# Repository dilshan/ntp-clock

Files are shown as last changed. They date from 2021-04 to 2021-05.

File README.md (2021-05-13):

# NTP based digital clock panel

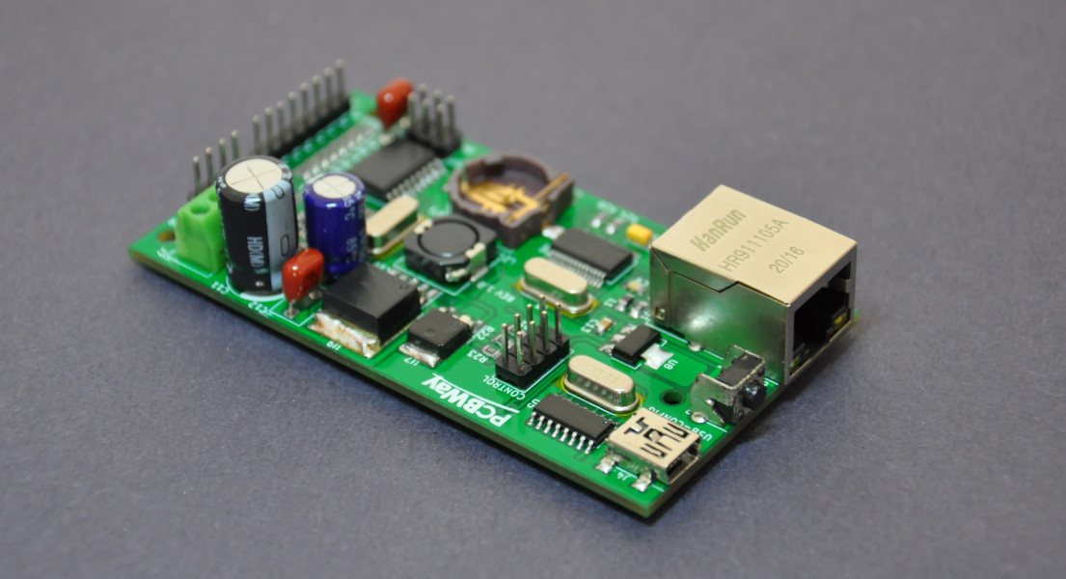
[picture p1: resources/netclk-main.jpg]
Prototype version of NTP clock driver


This project introduces an open-source, *ATmega328* based, configurable [NTP](https://en.wikipedia.org/wiki/Network_Time_Protocol) clock with a 2.3-inch, 7-segment display driver. This clock automatically obtains time from the configured NTP server and updates the date and time of the built-in RTC (*real-time clock*). If the connection to the NTP server is lost, the clock continues to run using its built-in RTC.

All the parameters of this clock can configure using its USB base serial terminal. The firmware of this clock supports both *static* and *DHCP* addressing modes. Apart from that, parameters such as NTP server address, time-offset, and clock display formats can change through the menu-driven configuration terminal.

This clock is designed to drive large common-anode, 7-segment displays. The prototype version is assembled using four individual segments of 7.2V, 2.3-inch, red color displays (*FJS23101BH*). To archive, the necessary high output voltage and the current, the 7-segment display output stage of this clock is formed using *ULN2803* Darlington transistor array and *BC858* transistors.

The network component of this clock is built around the *ENC28J60* 10BASE-T stand-alone Ethernet controller.

Highly accurate *DS3231M* RTC is using in this clock for time-keeping operations. To backup the date and time, the *CR1220* type button cell is included in the PCB. The date and time are syncs with the NTP server during the system startup. Users can manually initiate synchronization by pressing the "*SYNC*" button in the system.

Depending on the NTP server, the user needs to specify the time offset to the system to get the correct local time. Time offset can configure using the system configuration menu, and it must be input in a standard format like *+5:30*.

Firmware of this clock is developed using the [Arduino framework](https://www.arduino.cc/en/software) and libraries.

[**PCBWay**](https://www.pcbway.com) provides sponsorship for this project. The [PCBWay online ordering service](https://www.pcbway.com/orderonline.aspx) provides excellent help to fabricate this PCB. We got finished PCBs within three days, and the quality of the service is at a superior level. PCB of this project can directly [order from PCBWay through this link](https://www.pcbway.com/project/shareproject/NTP_based_digital_clock_panel.html).

This project is a [certified](https://certification.oshwa.org/lk000009.html) open-source hardware project. All the content of this project are distributed under the terms of the following license:

- Hardware License: [CC BY 4.0](https://creativecommons.org/licenses/by/4.0/)
- Software and firmware License: [MIT](https://github.com/dilshan/ntp-clock/blob/main/LICENSE)
- [Documentation](https://github.com/dilshan/ntp-clock/wiki) License: [CC BY 4.0](https://creativecommons.org/licenses/by/4.0/)

LK000009 (https://certification.oshwa.org/lk000009.html)

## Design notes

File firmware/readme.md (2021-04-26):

To compile the firmware following libraries must install into the Arduino IDE:

- [EtherCard](https://github.com/njh/EtherCard)
- [DS3231 library for the Arduino - *ds3231FS*](https://github.com/rodan/ds3231)
- [jm_PCF8574 Arduino Library](https://github.com/jmparatte/jm_PCF8574)

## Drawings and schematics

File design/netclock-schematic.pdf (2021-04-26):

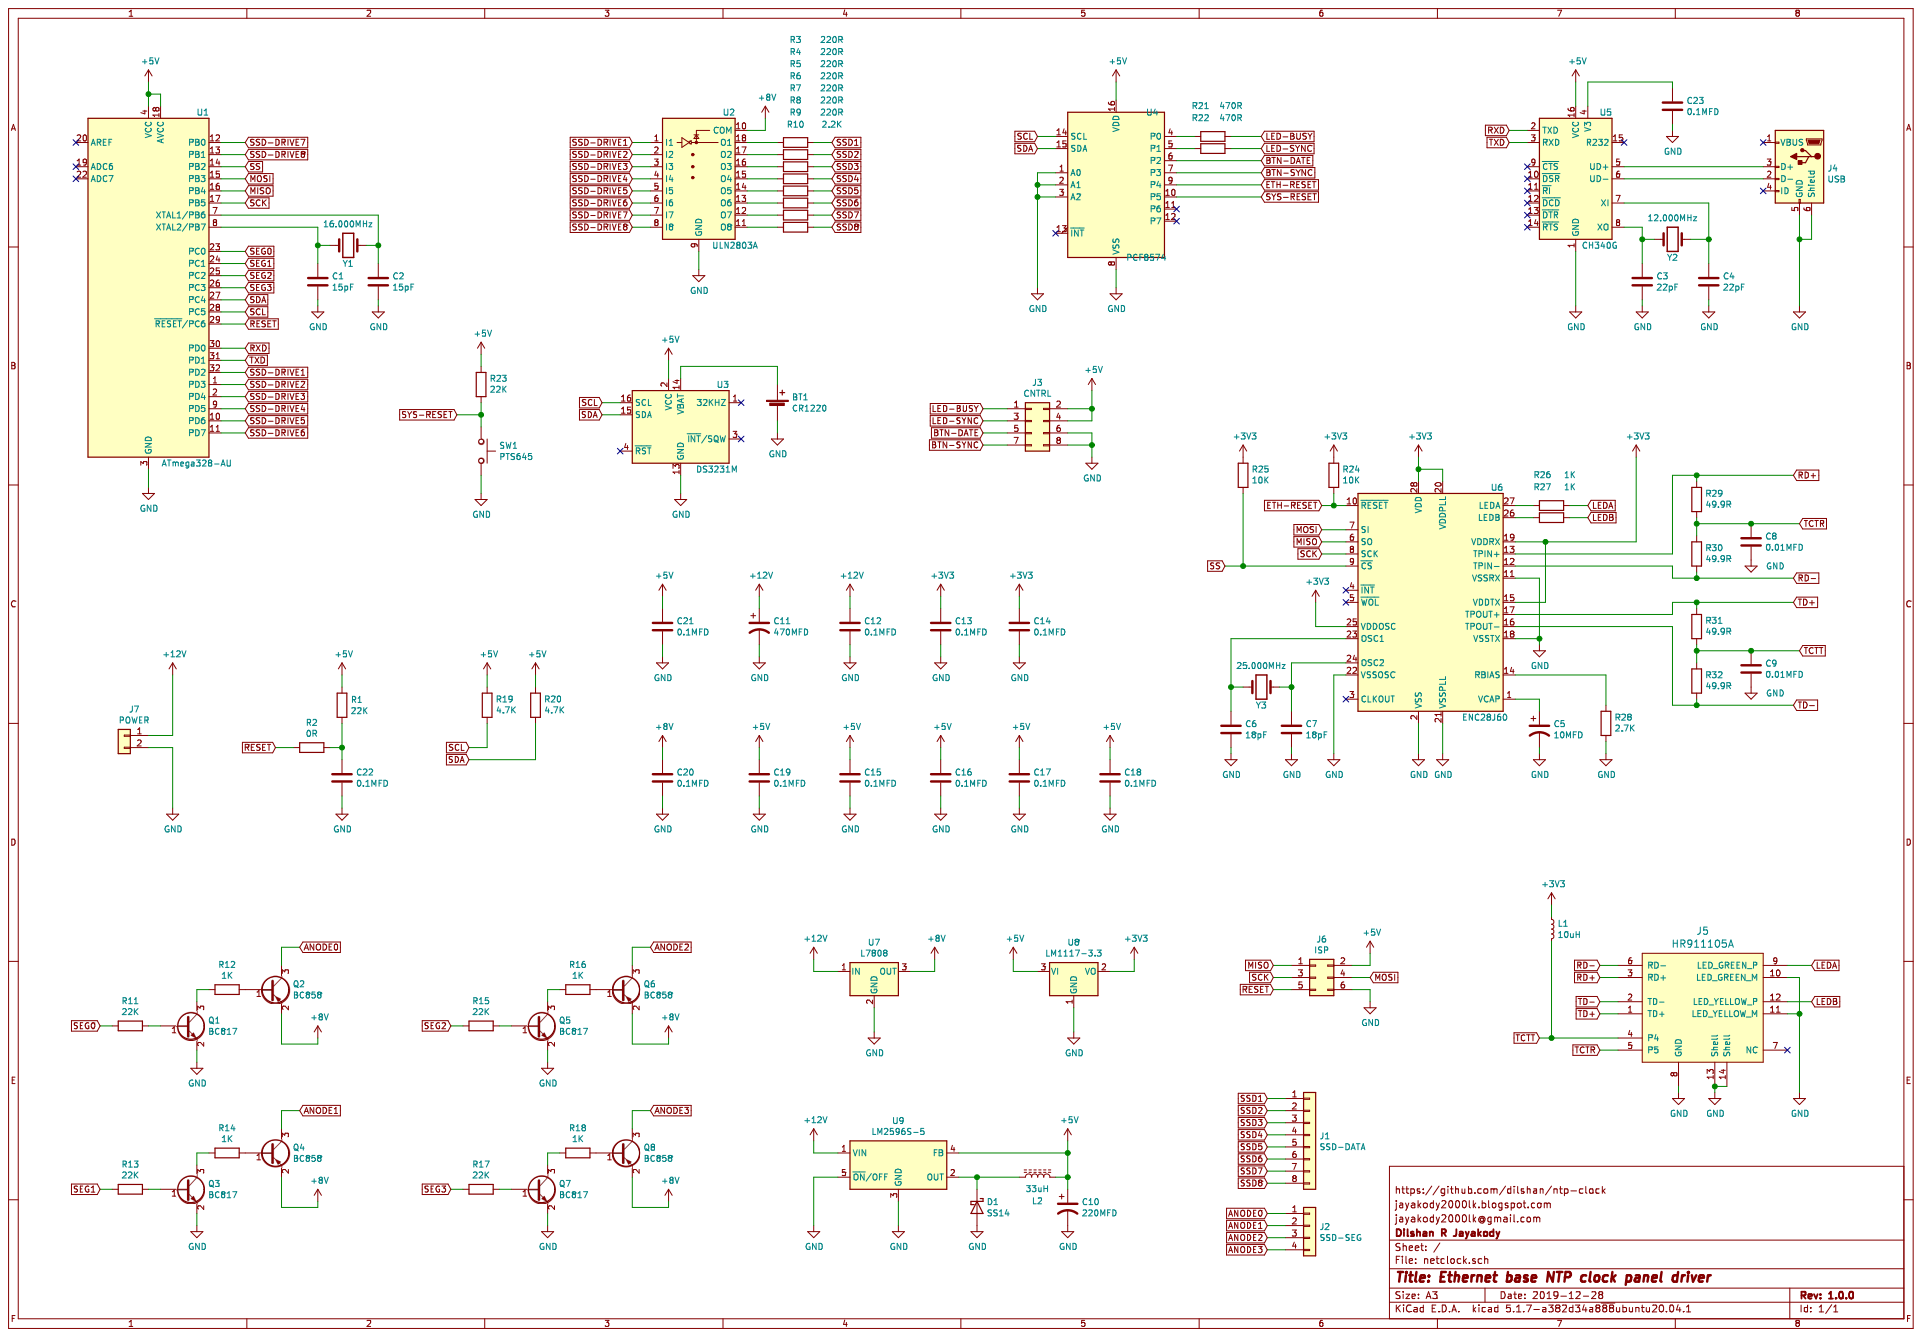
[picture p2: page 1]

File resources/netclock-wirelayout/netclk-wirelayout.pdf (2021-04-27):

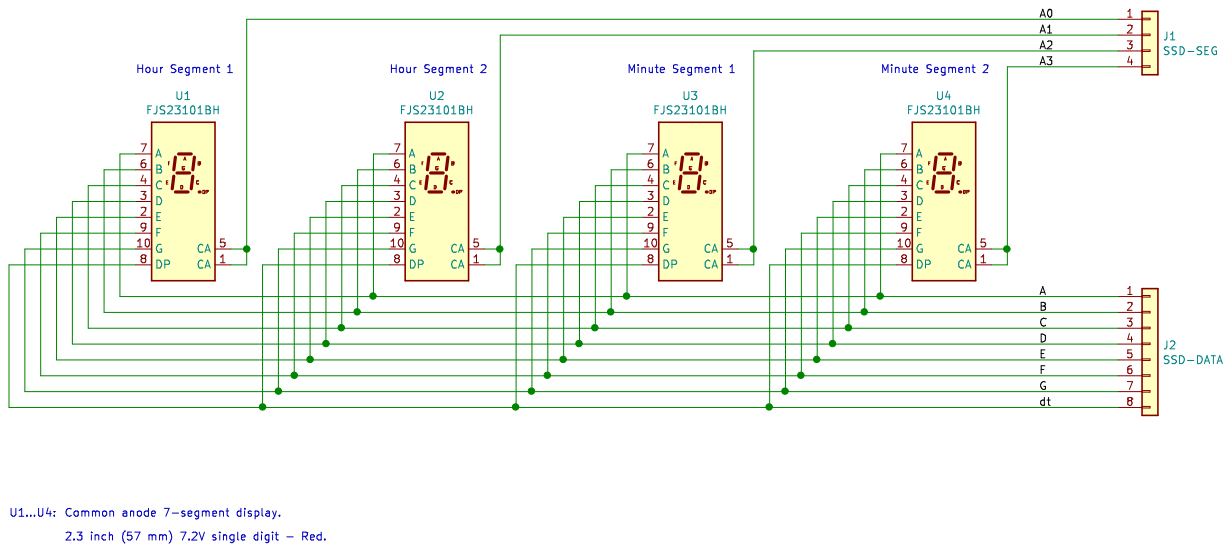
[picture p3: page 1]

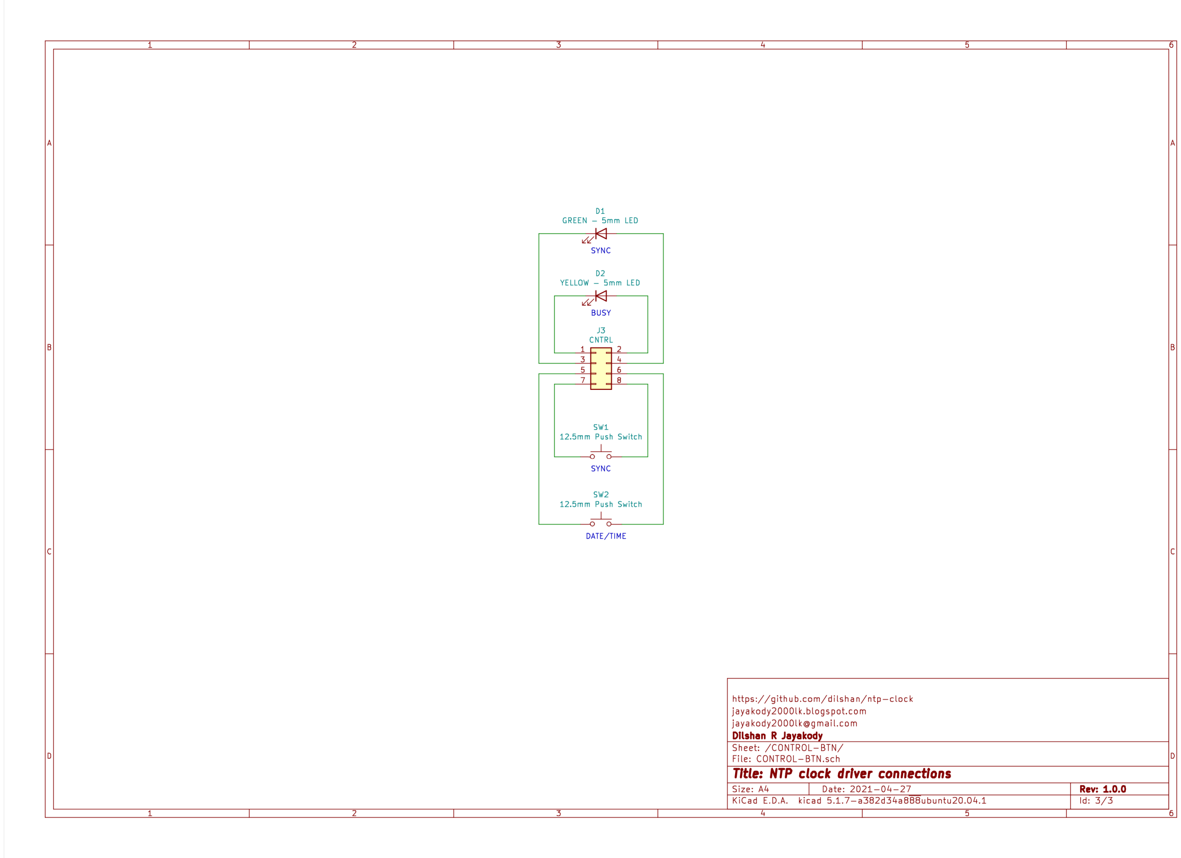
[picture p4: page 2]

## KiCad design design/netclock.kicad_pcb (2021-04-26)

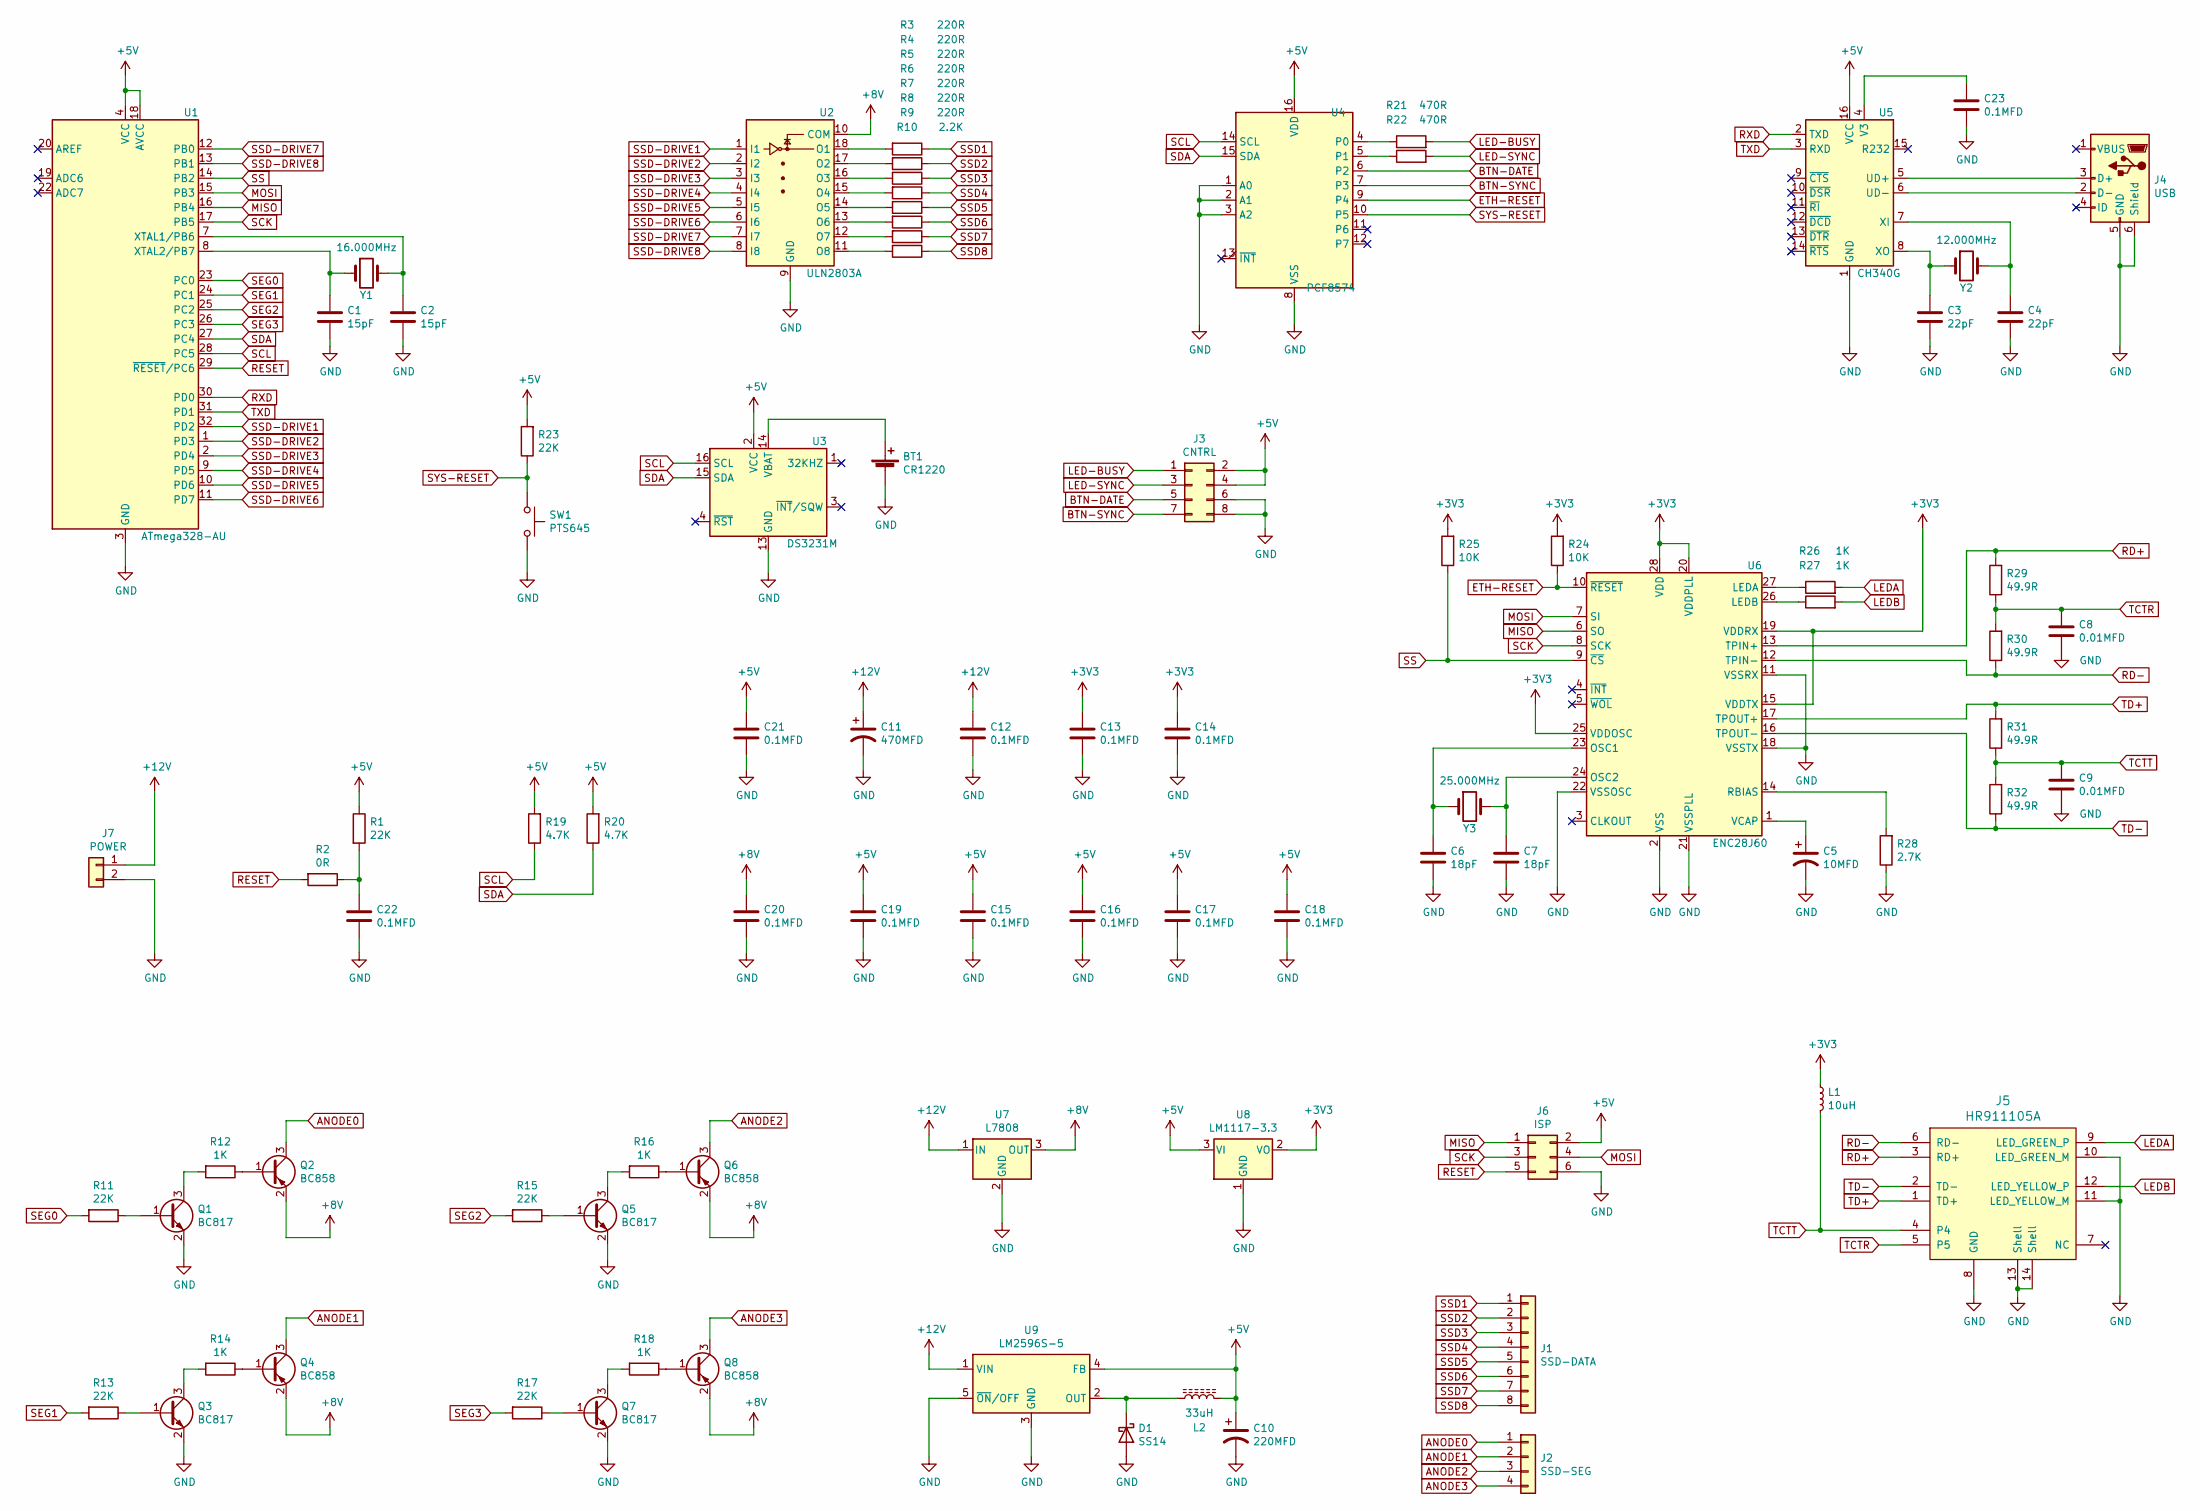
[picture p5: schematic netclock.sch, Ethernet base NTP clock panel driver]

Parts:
BT1: CR1220; BAT_BC501SM
C1, C2: 15pF; C_0805_2012Metric_Pad1.15x1.40mm_HandSolder
C3, C4: 22pF; C_0805_2012Metric_Pad1.15x1.40mm_HandSolder
C5: 10MFD; CP_EIA-3216-18_Kemet-A_Pad1.58x1.35mm_HandSolder
C6, C7: 18pF; C_0805_2012Metric_Pad1.15x1.40mm_HandSolder
C8, C9: 0.01MFD; C_0805_2012Metric_Pad1.15x1.40mm_HandSolder
C10: 220MFD; CP_Radial_D8.0mm_P5.00mm
C11: 470MFD; CP_Radial_D10.0mm_P5.00mm
C12: 0.1MFD; C_Disc_D7.5mm_W5.0mm_P5.00mm
C13, C14, C15, C16, C17, C18, C19, C21, C22, C23: 0.1MFD; C_0805_2012Metric_Pad1.15x1.40mm_HandSolder
C20: 0.1MFD; C_Disc_D6.0mm_W4.4mm_P5.00mm
D1: SS14; D_SMA
J1: SSD-DATA; PinHeader_1x08_P2.54mm_Vertical
J2: SSD-SEG; PinHeader_1x04_P2.54mm_Vertical
J3: CNTRL; PinHeader_2x04_P2.54mm_Vertical
J4: USB; USB_Mini-B_Lumberg_2486_01_Horizontal
J5: HR911105A; HR911105a
J6: ISP; PinHeader_2x03_P2.54mm_Vertical
J7: POWER; PhoenixContact_MCV_1,5_2-G-3.5_1x02_P3.50mm_Vertical
L1: 10uH; L_0805_2012Metric_Pad1.15x1.40mm_HandSolder
L2: 33uH; L_10.4x10.4_H4.8
Q1, Q3, Q5, Q7: BC817; SOT-23
Q2, Q4, Q6, Q8: BC858; SOT-23
R1, R11, R13, R15, R17, R23: 22K; R_0805_2012Metric_Pad1.15x1.40mm_HandSolder
R2: 0R; R_0805_2012Metric_Pad1.15x1.40mm_HandSolder
R3, R4, R5, R6, R7, R8, R9: 220R; R_0805_2012Metric_Pad1.15x1.40mm_HandSolder
R10: 2.2K; R_0805_2012Metric_Pad1.15x1.40mm_HandSolder
R12, R14, R16, R18, R26, R27: 1K; R_0805_2012Metric_Pad1.15x1.40mm_HandSolder
R19, R20: 4.7K; R_0805_2012Metric_Pad1.15x1.40mm_HandSolder
R21, R22: 470R; R_0805_2012Metric_Pad1.15x1.40mm_HandSolder
R24, R25: 10K; R_0805_2012Metric_Pad1.15x1.40mm_HandSolder
R28: 2.7K; R_0805_2012Metric_Pad1.15x1.40mm_HandSolder
R29, R30, R31, R32: 49.9R; R_0805_2012Metric_Pad1.15x1.40mm_HandSolder
SW1: PTS645; SW_Tactile_SPST_Angled_PTS645Vx31-2LFS
U1: ATmega328-AU; TQFP-32_7x7mm_P0.8mm
U2: ULN2803A; SOIC-18W_7.5x11.6mm_P1.27mm
U3: DS3231M; SOIC-16W_7.5x10.3mm_P1.27mm
U4: PCF8574; SOIC-16W_7.5x10.3mm_P1.27mm
U5: CH340G; SOIC-16_3.9x9.9mm_P1.27mm
U6: ENC28J60; SSOP-28_5.3x10.2mm_P0.65mm
U7: L7808; TO-252-3_TabPin2
U8: LM1117-3.3; SOT-223-3_TabPin2
U9: LM2596S-5; TO-263-5_TabPin3
Y1: 16.000MHz; Crystal_HC49-U_Vertical
Y2: 12.000MHz; Crystal_HC49-U_Vertical
Y3: 25.000MHz; Crystal_HC49-U_Vertical

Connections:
+3V3: C13.1, C14.1, L1.1, R24.2, R25.2, U6.15 (VDDTX), U6.19 (VDDRX), U6.20 (VDDPLL), U6.25 (VDDOSC), U6.28 (VDD), U8.2 (VO)
+5V: C10.1, C15.1, C16.1, C17.1, C18.1, C19.1, C21.1, J3.2, J3.4, J6.2, L2.2, R1.1, R19.2, R20.2, R23.2, U1.4 (VCC), U1.6 (VCC), U1.18 (AVCC), U3.2 (VCC), U4.16 (VDD), U5.16 (VCC), U8.3 (VI), U9.4 (FB)
+8V: C20.1, Q2.2 (E), Q4.2 (E), Q6.2 (E), Q8.2 (E), U2.10 (COM), U7.3 (OUT)
+12V: C11.1, C12.1, J7.1, U7.1 (IN), U9.1 (VIN)
ANODE0: J2.1, Q2.3 (C)
ANODE1: J2.2, Q4.3 (C)
ANODE2: J2.3, Q6.3 (C)
ANODE3: J2.4, Q8.3 (C)
BTN-DATE: J3.5, U4.6 (P2)
BTN-SYNC: J3.7, U4.7 (P3)
ETH-RESET: R24.1, U4.9 (P4), U6.10 (~RESET)
GND: BT1.2 (-), C1.2, C2.2, C3.2, C4.2, C5.2, C6.2, C7.2, C8.2, C9.2, C10.2, C11.2, C12.2, C13.2, C14.2, C15.2, C16.2, C17.2, C18.2, C19.2, C20.2, C21.2, C22.2, C23.2, D1.2 (A), J3.6, J3.8, J4.5 (GND), J4.6 (Shield), J5.8 (GND), J5.10 (LED_GREEN_M), J5.11 (LED_YELLOW_M), J5.13 (Shell), J5.14 (Shell), J6.6, J7.2, Q1.2 (E), Q3.2 (E), Q5.2 (E), Q7.2 (E), R28.1, SW1.2, U1.3 (GND), U1.5 (GND), U1.21 (GND), U2.9 (GND), U3.5 (GND), U3.6 (GND), U3.7 (GND), U3.8 (GND), U3.9 (GND), U3.10 (GND), U3.11 (GND), U3.12 (GND), U3.13 (GND), U4.1 (A0), U4.2 (A1), U4.3 (A2), U4.8 (VSS), U5.1 (GND), U6.2 (VSS), U6.11 (VSSRX), U6.18 (VSSTX), U6.21 (VSSPLL), U6.22 (VSSOSC), U7.2 (GND), U8.1 (GND), U9.3 (GND), U9.5 (~ON~/OFF)
LED-BUSY: J3.1, R21.2
LED-SYNC: J3.3, R22.2
LEDA: J5.9 (LED_GREEN_P), R27.2
LEDB: J5.12 (LED_YELLOW_P), R26.2
MISO: J6.1, U1.16 (PB4), U6.6 (SO)
MOSI: J6.4, U1.15 (PB3), U6.7 (SI)
unnamed: BT1.1 (+), U3.14 (VBAT)
unnamed: C1.1, U1.8 (XTAL2/PB7), Y1.1
unnamed: C2.1, U1.7 (XTAL1/PB6), Y1.2
unnamed: C3.1, U5.8 (XO), Y2.1
unnamed: C4.1, U5.7 (XI), Y2.2
unnamed: C5.1, U6.1 (VCAP)
unnamed: C6.1, U6.23 (OSC1), Y3.1
unnamed: C7.1, U6.24 (OSC2), Y3.2
unnamed: C22.1, R1.2, R2.1
unnamed: C23.1, U5.4 (V3)
unnamed: D1.1 (K), L2.1, U9.2 (OUT)
unnamed: J4.2 (D-), U5.6 (UD-)
unnamed: J4.3 (D+), U5.5 (UD+)
unnamed: Q1.1 (B), R11.1
unnamed: Q1.3 (C), R12.2
unnamed: Q2.1 (B), R12.1
unnamed: Q3.1 (B), R13.1
unnamed: Q3.3 (C), R14.2
unnamed: Q4.1 (B), R14.1
unnamed: Q5.1 (B), R15.1
unnamed: Q5.3 (C), R16.2
unnamed: Q6.1 (B), R16.1
unnamed: Q7.1 (B), R17.1
unnamed: Q7.3 (C), R18.2
unnamed: Q8.1 (B), R18.1
unnamed: R3.2, U2.18 (O1)
unnamed: R4.2, U2.17 (O2)
unnamed: R5.2, U2.16 (O3)
unnamed: R6.2, U2.15 (O4)
unnamed: R7.2, U2.14 (O5)
unnamed: R8.2, U2.13 (O6)
unnamed: R9.2, U2.12 (O7)
unnamed: R10.2, U2.11 (O8)
unnamed: R21.1, U4.4 (P0)
unnamed: R22.1, U4.5 (P1)
unnamed: R26.1, U6.26 (LEDB)
unnamed: R27.1, U6.27 (LEDA)
unnamed: R28.2, U6.14 (RBIAS)
RD+: J5.3 (RD+), R29.2, U6.13 (TPIN+)
RD-: J5.6 (RD-), R30.1, U6.12 (TPIN-)
RESET: J6.5, R2.2, U1.29 (~RESET~/PC6)
RXD: U1.30 (PD0), U5.2 (TXD)
SCK: J6.3, U1.17 (PB5), U6.8 (SCK)
SCL: R19.1, U1.28 (PC5), U3.16 (SCL), U4.14 (SCL)
SDA: R20.1, U1.27 (PC4), U3.15 (SDA), U4.15 (SDA)
SEG0: R11.2, U1.23 (PC0)
SEG1: R13.2, U1.24 (PC1)
SEG2: R15.2, U1.25 (PC2)
SEG3: R17.2, U1.26 (PC3)
SS: R25.1, U1.14 (PB2), U6.9 (~CS)
SSD1: J1.1, R3.1
SSD2: J1.2, R4.1
SSD3: J1.3, R5.1
SSD4: J1.4, R6.1
SSD5: J1.5, R7.1
SSD6: J1.6, R8.1
SSD7: J1.7, R9.1
SSD8: J1.8, R10.1
SSD-DRIVE1: U1.32 (PD2), U2.1 (I1)
SSD-DRIVE2: U1.1 (PD3), U2.2 (I2)
SSD-DRIVE3: U1.2 (PD4), U2.3 (I3)
SSD-DRIVE4: U1.9 (PD5), U2.4 (I4)
SSD-DRIVE5: U1.10 (PD6), U2.5 (I5)
SSD-DRIVE6: U1.11 (PD7), U2.6 (I6)
SSD-DRIVE7: U1.12 (PB0), U2.7 (I7)
SSD-DRIVE8: U1.13 (PB1), U2.8 (I8)
SYS-RESET: R23.1, SW1.1, U4.10 (P5)
TCTR: C8.1, J5.5, R29.1, R30.2
TCTT: C9.1, J5.4, L1.2, R31.1, R32.2
TD+: J5.1 (TD+), R31.2, U6.17 (TPOUT+)
TD-: J5.2 (TD-), R32.1, U6.16 (TPOUT-)
TXD: U1.31 (PD1), U5.3 (RXD)

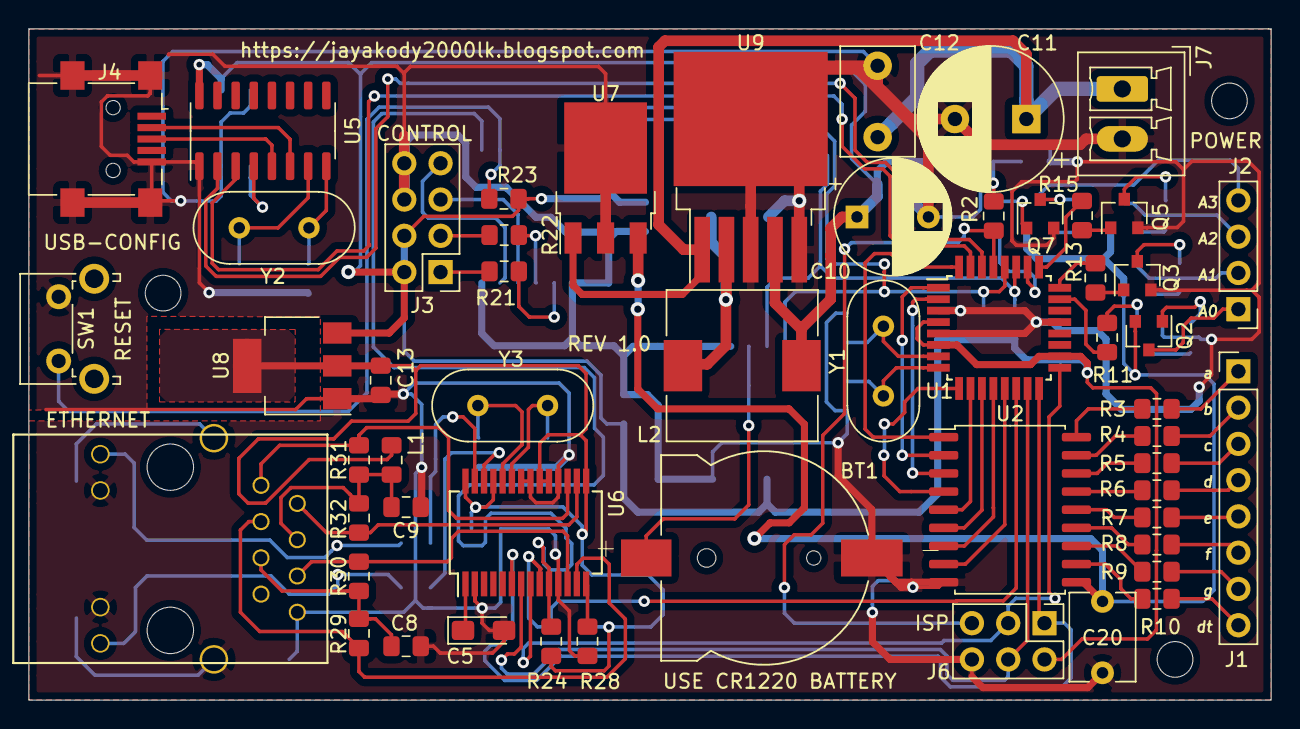
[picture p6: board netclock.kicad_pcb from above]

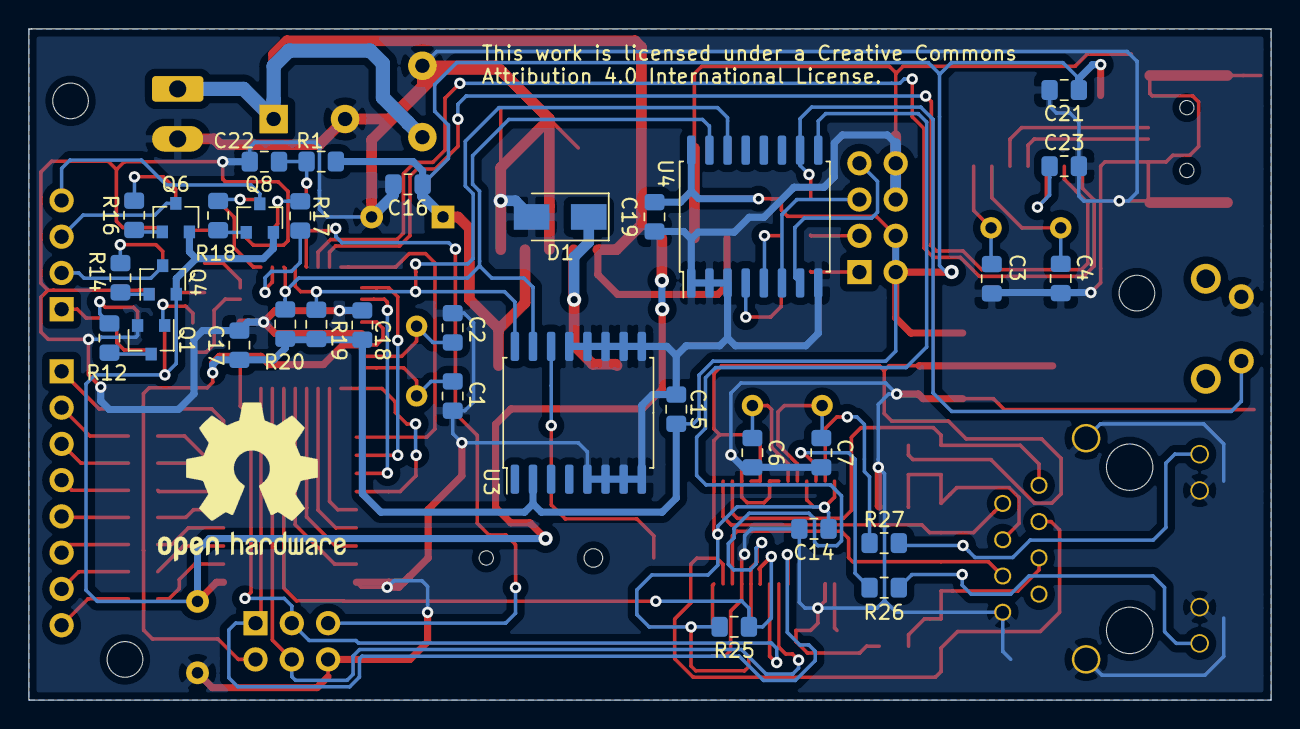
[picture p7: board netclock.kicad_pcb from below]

Board: 2 copper layers, 87.0 x 47.0 mm, 91 parts (34 on the bottom side), 90 nets.

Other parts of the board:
 : OSHW-Logo2_14.6x12mm_SilkScreen
 #2,  #3,  #4: MountingHole_2.5mm

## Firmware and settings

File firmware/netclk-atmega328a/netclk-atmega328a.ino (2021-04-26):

//---------------------------------------------------------------------------------------
// Ethernet base NTP clock panel driver.
// Main Arduino sketch.
// 
// Copyright (c) 2021 Dilshan R Jayakody. [jayakody2000lk@gmail.com]
// 
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
#include <Wire.h>
#include <EtherCard.h>
#include <ds3231.h>

#include "netclkdisplay.h"
#include "netclkintf.h"
#include "netclkstorage.h"
#include "netclkutil.h"

// Use NIST Internet Time Server (time-a-g.nist.gov).
#define DEFAULT_NTP_PORT  123
#define DEFAULT_NTP_SERVER  {129, 6, 15, 28}

// Unix timestamp for 1st of January, 1970 (UTC).
#define UNIX_TIMESTAMP  2208988800UL
#define BASE_YEAR       1970

#define LEAP_YEAR(Y)  (((BASE_YEAR+(Y))>0) && !((BASE_YEAR+(Y))%4) && (((BASE_YEAR+(Y))%100) || !((BASE_YEAR+(Y))%400)))
#define NEW_LINE      Serial.println(F(" "))

// Device MAC address generated by  Ian Campbell's MAC address generator
// at https://www.hellion.org.uk/cgi-bin/randmac.pl.
static const unsigned char DEV_MAC[] = {0x3A, 0xF5, 0x42, 0x21, 0x96, 0x33};

// Number of days in each month.
static const unsigned char monthDays[] = {31, 28, 31, 30, 31, 30, 31, 31, 30, 31, 30, 31};

bool isNetworkAvailable;
bool clock24hrFormat;
bool initalBoot;
static volatile bool updateReq;

unsigned char syncButtonState;
unsigned char dateButtonState;
unsigned char displayTimeout;

unsigned char ntpServer[] = DEFAULT_NTP_SERVER;
unsigned char ntpPort = DEFAULT_NTP_PORT;
unsigned char Ethernet::buffer[450];

static unsigned char displayVal[3];

long timeZoneOffset = 0L;

struct ts systime;
SystemConfig sysconf;
static volatile DISPLAY_MODE displayMode;

void resetSysConfig()
{
  SystemConfig resetConfig;
  const unsigned char resetNTPIP[] = DEFAULT_NTP_SERVER;

  setDefaultConfig(&resetConfig);

  // Network type is set to DHCP and set static IP configuration entries.
  configWriteNetworkType(resetConfig.networkType);
  configWriteDeviceIP(resetConfig.deviceIP);
  configWriteSubnetMask(resetConfig.netmask);
  configWriteGateway(resetConfig.gateway);

  // Set default NTP server configuration.
  configureNTPInfo(resetNTPIP, DEFAULT_NTP_PORT);

  // Reset time zone to 0:00.
  writeTimeOffset(0L);

  // Time display format is set to 24-hour.
  writeDisplayFormat(true);

  delay(100);
}

void initSystem()
{
  setDefaultConfig(&sysconf);

  // Setup seven segment display interface.
  initDisplay();

  // Setup serial communication interface with baud rate of 9600 and 8N1 configuration.
  Serial.begin(9600);
  Serial.println(F("Starting up the system..."));

  // Setup I2C interface.
  Wire.begin();

  // Setup PCF8574 I/O expander and it's I/O ports.
  delay(100);
  initInterface();
  setIndicator(IND_BUSY_CONFIG, true);

  // Check for factory reset input.
  if (!getFactorResetState())
  {
    // Perform configuration reset.
    Serial.println(F("Reseting system to default configuration..."));
    resetSysConfig();

    // Wait until user releases reset jumper.
    while (!getFactorResetState())
    {
      setIndicator(IND_BUSY_CONFIG, false);
      delay(250);
      setIndicator(IND_BUSY_CONFIG, true);
      delay(250);
    }

    // Perform system restart.
    rebootSystem();
  }

  // Load system configuration from EEPROM.
  Serial.println(F("Reading system configuration..."));
  configRead(&sysconf);
  readNTPConfigInfo(ntpServer, &ntpPort);

  // Validate NTP configuration.
  if ((ntpServer[0] == 0xFF) && (ntpServer[1] == 0xFF) && (ntpServer[2] == 0xFF) && (ntpServer[3] == 0xFF))
  {
    // EEPROM default is loaded. Fix NTP IP address and port to default values.
    Serial.println(F("Switching NTP server configuration to defaults..."));
    unsigned char tempDefaultIP[] = DEFAULT_NTP_SERVER;
    memcpy(ntpServer, tempDefaultIP, 4);
    ntpPort = DEFAULT_NTP_PORT;
  }

  // Setup ethernet controller.
  Serial.println(F("Connecting to network..."));
  ether.begin(sizeof Ethernet::buffer, DEV_MAC, SS);
}

void configureDHCP(SystemConfig *config)
{
  config->networkType = NET_TYPE_DHCP;
  configWriteNetworkType(NET_TYPE_DHCP);

  Serial.println(F("Configuration updated with DHCP settings."));
}

bool configureStaticIP(SystemConfig *config)
{
  // Prompt IP address, subnet mask and gatway IP address inputs to user.
  Serial.print(F("Device IP address: "));
  if (!inputIpAddress(config->deviceIP))
  {
    return false;
  }

  Serial.print(F("\n\n\rSubnet mask: "));
  if (!inputIpAddress(config->netmask))
  {
    return false;
  }

  Serial.print(F("\n\n\rGateway IP address: "));
  if (!inputIpAddress(config->gateway))
  {
    return false;
  }

  NEW_LINE;

  // Write configuration changes to EEPROM.
  config->networkType = NET_TYPE_STATIC;
  configWriteNetworkType(NET_TYPE_STATIC);
  configWriteDeviceIP(config->deviceIP);
  configWriteSubnetMask(config->netmask);
  configWriteGateway(config->gateway);

  Serial.println(F("Configuration updated with static IP address."));
  return true;
}

bool configureNTPServer(unsigned char* ntpIpAddr, unsigned char* ntpPort)
{
  unsigned char tempIp[4] = DEFAULT_NTP_SERVER;
  unsigned char tempPort = DEFAULT_NTP_PORT;

  int retryAttempt = 60;
  unsigned long ntpTempVal = 0;

  // Prompt NTP IP address.
  Serial.print(F("NTP server IP address: "));
  if (!inputIpAddress(tempIp))
  {
    return false;
  }

  // Prompt NTP port.
  Serial.print(F("\n\n\rNTP server port: "));
  if (!inputPort(&tempPort, DEFAULT_NTP_PORT))
  {
    return false;
  }

  // Verify specified NTP server.
  Serial.println(F("\n\n\rConnecting with the specified NTP server..."));
  while (retryAttempt > 0)
  {
    ether.ntpRequest(tempIp, tempPort);
    Serial.print(".");
    word length = ether.packetReceive();
    ether.packetLoop(length);
    if (length > 0 && ether.ntpProcessAnswer(&ntpTempVal, tempPort))
    {
      // NTP request is completed.
      Serial.println(F("\n\rReceived data from NTP server\n\r"));
      break;
    }

    delay(500);
    retryAttempt--;
  }

  // Validate response received from the request.
  if (ntpTempVal > 0)
  {
    // NTP request is successful.
    memcpy(ntpIpAddr, tempIp, 4);
    *ntpPort = tempPort;
    return true;
  }
  else
  {
    // NTP request is failed.
    Serial.println(F("\n\rNTP request is failed or invalid!\n\r"));
    return false;
  }
}

bool setDisplayFormat()
{
  bool isContinue = true;
  char inKey;

  while (isContinue)
  {
    inKey = 0;

    Serial.println(F("1. Display time in 24-hour format"));
    Serial.println(F("2. Display time in 12-hour format"));
    Serial.println("");
    Serial.print(F("Selection [1..2]: "));

    inKey = getKeyInput(0x30, 0x33);
    {
      if (inKey == 0x1B)
      {
        // User cancel the current operation.
        return false;
      }
    }

    Serial.println(inKey);

    // Allow key option 1 or 2 only.
    isContinue = !((inKey > 0x30) && (inKey < 0x33));
  }

  clock24hrFormat = (inKey == 0x31);
  return true;
}

void systemMenu()
{
  bool isContinue = true;
  char inKey;
  long tempTimeZone;

  // Initialize menu system and start menu service loop.
  setIndicator(IND_BUSY_CONFIG, true);
  NEW_LINE;

  while (isContinue)
  {
    inKey = 0;

    Serial.println(F("1. Configure for DHCP network"));
    Serial.println(F("2. Configure with static IP address"));
    Serial.println(F("3. Show network configuration"));
    Serial.println(F("4. Synchronize date/time"));
    Serial.println(F("5. Set time offset"));
    Serial.println(F("6. Show current date/time"));
    Serial.println(F("7. Configure NTP server"));
    Serial.println(F("8. Configure clock display format"));
    Serial.println(F("9. Exit"));
    Serial.println(F("0. Exit and restart"));
    Serial.println("");
    Serial.print(F("Selection [0..9]: "));

    inKey = getKeyInput(0x2F, 0x3A);

    if ((inKey > 0x2F) && (inKey < 0x3A))
    {
      Serial.println(inKey);
      NEW_LINE;
    }

    switch (inKey)
    {
      case 0x31:
        // Configure for DHCP network.
        configureDHCP(&sysconf);
        Serial.println(F("Restarting the system to apply the network changes..."));
        rebootSystem();
        break;
      case 0x32:
        // Configure with static IP address.
        if (configureStaticIP(&sysconf))
        {
          // Static IP configuration is completed.
          Serial.println(F("Restarting the system to apply the network changes..."));
          rebootSystem();
        }
        else
        {
          // Static IP configuration is canceled by the user.
          Serial.println(F("\n\n"));
        }
        break;
      case 0x33:
        // Show network configuration.
        showNetworkInfo();
        break;
      case 0x34:
        // Synchronize date/time.
        clearDisplay();
        syncSystemTime();
        NEW_LINE;
        break;
      case 0x35:
        // Set time offset.
        Serial.print(F("Time offset relative to UTC/GMT [e.g: +5:30]: "));
        tempTimeZone = inputTimeZone();
        NEW_LINE;
        if (tempTimeZone != 1)
        {
          // Time zone configuration is completed.
          timeZoneOffset = tempTimeZone;
          writeTimeOffset(timeZoneOffset);
          Serial.println(F("Restarting the system to apply the time offset change..."));
          rebootSystem();
        }
        else
        {
          // Time zone configuration is canceled by the user.
          NEW_LINE;
        }
        break;
      case 0x36:
        // Show current date/time.
        printCurrentTimeConfig();
        NEW_LINE;
        break;
      case 0x37:
        // Configure NTP server.
        if (configureNTPServer(ntpServer, &ntpPort))
        {
          // NTP server configuration is completed.
          configureNTPInfo(ntpServer, ntpPort);
        }
        else
        {
          // NTP server configuration is canceled by the user.
          Serial.println(F("\n\n"));
        }
        break;
      case 0x38:
        // Configure clock display format.
        if (setDisplayFormat())
        {
          writeDisplayFormat(clock24hrFormat);
        }
        NEW_LINE;
        break;
      case 0x39:
      case 0x1B:
        // Exit.
        isContinue = false;
        break;
      case 0x30:
        // Exit and restart.
        Serial.println("");
        rebootSystem();
        break;
    }
  }

  // Leaving from configuration menu system.
  NEW_LINE;
  updateReq = true;
  displayMode = DISP_TIME;
  setIndicator(IND_BUSY_CONFIG, false);
}

unsigned long getTimeFromServer()
{
  unsigned long timeFromNTP;

  int retryAttempt = 60;
  while (retryAttempt > 0)
  {
    ether.ntpRequest(ntpServer, ntpPort);
    Serial.print(".");
    word length = ether.packetReceive();
    ether.packetLoop(length);
    if (length > 0 && ether.ntpProcessAnswer(&timeFromNTP, ntpPort))
    {
      // NTP request is successful.
      Serial.println();
      Serial.println(F("Received time from server"));
      return timeFromNTP - UNIX_TIMESTAMP + timeZoneOffset;
    }

    delay(500);
    retryAttempt--;
  }

  return 0;
}

void epochToTime(unsigned long time, struct ts* outTime)
{
  unsigned char year;
  unsigned char month, monthLength;
  unsigned long days;

  // Extract time components from specified data.
  outTime->sec = time % 60;
  time /= 60;

  outTime->min = time % 60;
  time /= 60;

  outTime->hour = time % 24;
  time /= 24;

  year = 0;
  days = 0;

  // Calculate year from 1970.
  while ((unsigned)(days += (LEAP_YEAR(year) ? 366 : 365)) <= time)
  {
    year++;
  }

  outTime->year = year + BASE_YEAR;

  days -= LEAP_YEAR(year) ? 366 : 365;
  time -= days;

  days = 0;
  monthLength = 0;

  for (month = 0; month < 12; month++)
  {
    if (month == 1)
    {
      // Determine days in month of february based on leap year.
      monthLength = LEAP_YEAR(year) ? 29 : 28;
    }
    else
    {
      monthLength = monthDays[month];
    }

    if (time >= monthLength)
    {
      time -= monthLength;
    }
    else
    {
      break;
    }
  }

  outTime->mon = month + 1;
  outTime->mday = time + 1;
}

void showNetworkInfo()
{
  // Show status of the network connectivity.
  Serial.print(F("Network connection: "));
  if (isNetworkAvailable)
  {
    // Network connection is active.
    Serial.println(F("UP"));
    ether.printIp("Device IP address: ", ether.myip);
    ether.printIp("Netmask: ", ether.netmask);
    ether.printIp("Gateway IP address: ", ether.gwip);
    ether.printIp("DNS IP address: ", ether.dnsip);
  }
  else
  {
    // Network connection is down!
    Serial.println(F("DOWN"));
  }

  ether.printIp("NTP server: ", ntpServer);
  Serial.print(F("NTP server port: "));
  Serial.println(ntpPort);
  NEW_LINE;
}

void syncSystemTime()
{
  setIndicator(IND_SYNC, true);
  Serial.println(F("Trying to synchronize time with server..."));

  // Create DHCP or static IP based network connection.
  if (!isNetworkAvailable)
  {
    if (!initalBoot)
    {
      // If network is not available we need to restart the ENC28J64 controller.
      Serial.println(F("Connecting to network..."));
      resetEthernet();
      delay(1000);
      ether.begin(sizeof Ethernet::buffer, DEV_MAC, SS);
      delay(200);
    }

    // Try to create network connection.
    if (sysconf.networkType == NET_TYPE_DHCP)
    {
      // Create DHCP network connection.
      Serial.println(F("Requesting DHCP network connection"));
      isNetworkAvailable = ether.dhcpSetup();
      if (!isNetworkAvailable)
      {
        Serial.println(F("** Fail to create network connection! **"));
      }
    }
    else
    {
      // Create network connection with specified static IP.
      Serial.println(F("Configuring static IP connection"));
      isNetworkAvailable = ether.staticSetup(sysconf.deviceIP, sysconf.gateway, NULL, sysconf.netmask);
    }

    ether.printIp("- Device IP address: ", ether.myip);
    ether.printIp("- Netmask: ", ether.netmask);
    ether.printIp("- Gateway IP address: ", ether.gwip);
    ether.printIp("- DNS IP address: ", ether.dnsip);
  }

  // Sync RTC time using NTP server.
  if (isNetworkAvailable)
  {
    Serial.println(F("Establishing connection with time server..."));
    unsigned long tempTime = getTimeFromServer();

    if (tempTime != 0)
    {
      // Time sync is successful.
      epochToTime(tempTime, &systime);

      // Sync. RTC time with NTP time.
      DS3231_set(systime);
      Serial.println(F("Real-time clock is now synchronized with server time"));
    }
    else
    {
      // Time sync is fail due to timeout, network issue or configuration issues.
      Serial.println(F("\n\rUnable to synchronize time with specified server!"));
      isNetworkAvailable = false;
    }
  }
  else
  {
    // Time sync is fail due to network connection issues.
    Serial.println(F("Time server synchronize failed due to network error!"));
  }

  setIndicator(IND_SYNC, false);
}

void printCurrentTimeConfig()
{
  DS3231_get(&systime);

  // Print current system time.
  Serial.print(F("Time: "));
  Serial.print(systime.hour);
  Serial.print(F(":"));
  Serial.print(systime.min);
  Serial.print(F(":"));
  Serial.print(systime.sec);
  NEW_LINE;

  // Print current system date.
  Serial.print(F("Date: "));
  Serial.print(systime.year);
  Serial.print(F("/"));
  Serial.print(systime.mon);
  Serial.print(F("/"));
  Serial.print(systime.mday);
  NEW_LINE;
}

void setup()
{
  // Initialize global variables.
  initalBoot = true;
  isNetworkAvailable = false;
  updateReq = false;
  clock24hrFormat = true;

  displayVal[0] = 0;
  displayVal[1] = 0;
  displayVal[2] = 0;

  syncButtonState = 0;
  dateButtonState = 0;

  displayMode = DISP_TIME;

  // Initializing the system.
  initSystem();

  // Initializing RTC.
  Serial.println(F("Configuring and starting real-time clock"));
  DS3231_init(DS3231_INTCN);

  // Get time offset from configuration.
  timeZoneOffset = readTimeOffset();
  if (timeZoneOffset == -1)
  {
    timeZoneOffset = 0L;
  }

  syncSystemTime();
  delay(100);

  // Get time from RTC.
  Serial.println(F("Receiving time from real-time clock..."));
  DS3231_get(&systime);

  // Check RTC values to detect RTC battery status.
  if (systime.year == 1900)
  {
    // RTC reset detetced. Set default time in RTC.
    systime.mday = 1;
    systime.mon = 1;
    systime.year = 2020;
    systime.hour = 1;
    systime.min = 0;
    systime.sec = 0;

    DS3231_set(systime);
  }

  Serial.print(systime.mday);
  Serial.print(F("-"));
  Serial.print(systime.mon);
  Serial.print(F("-"));
  Serial.print(systime.year);
  Serial.print(F("   "));
  Serial.print(systime.hour);
  Serial.print(F(":"));
  Serial.print(systime.min);
  Serial.print(F(":"));
  Serial.println(systime.sec);

  // Get time display format.
  clock24hrFormat = readDisplayFormat();

  // Show current time in seven segment display.
  displayVal[0] = formatHours(clock24hrFormat, systime.hour);
  displayVal[1] = systime.min;
  displayVal[2] = systime.sec;

  // System initialization is completed.
  setIndicator(IND_BUSY_CONFIG, false);
  delay(100);
  activateRefreshTimer();
  initalBoot = false;
}

void loop()
{
  ether.packetLoop(ether.packetReceive());

  // Check status of the serial input buffer.
  if (Serial.available() > 0)
  {
    // System menu is accessible using <ENTER> or <SPACE> keys.
    unsigned char inKey = Serial.read();
    if ((inKey == 0x0D) || (inKey == 0x20))
    {
      // Open system configuration menu.
      clearDisplay();
      systemMenu();
    }
  }

  // Check for time update flag.
  if (updateReq)
  {
    updateReq = false;
    DS3231_get(&systime);

    switch (displayMode)
    {
      case DISP_TIME:
        // Display time;
        displayVal[0] = formatHours(clock24hrFormat, systime.hour);
        displayVal[1] = systime.min;
        displayVal[2] = systime.sec;
        break;
      case DISP_DATE:
        // Display day and month.
        displayVal[0] = systime.mon;
        displayVal[1] = systime.mday;
        displayVal[2] = 0;
        break;
      case DISP_SECONDS:
        // Display seconds.
        displayVal[0] = 0xFF;
        displayVal[1] = systime.sec;
        displayVal[2] = 0;
        break;
    }
  }

  // Update seven segment display with current time.
  if ((displayMode == DISP_TIME) || (displayMode == DISP_DATE))
  {
    displayTime(displayVal);
  }
  else
  {
    displaySeconds(displayVal);
  }

  // Check for SYNC button press event.
  if (!getSyncButtonState())
  {
    syncButtonState += (syncButtonState < 0xFF) ? 1 : 0;
  }
  else
  {
    if (syncButtonState > 0x10)
    {
      syncButtonState = 0;
      displayTimeout = 0;

      // Start time sync with NTP server.
      clearDisplay();
      syncSystemTime();

      // Refresh and show time in next render cycle.
      updateReq = true;
      displayMode = DISP_TIME;
    }
  }

  // Check for DATE/TIME button press event.
  if (!getDateButtonState())
  {
    dateButtonState++;

    if (dateButtonState >= 0xFE)
    {
      // In long press display seconds.
      dateButtonState = 1;
      displayTimeout = 0;

      displayVal[0] = 0xFF;
      displayVal[1] = systime.sec;
      displayVal[2] = 0;

      displayMode = DISP_SECONDS;
    }
  }
  else
  {
    // DATE/TIME button press event handler.
    if (dateButtonState > 0x10)
    {
      dateButtonState = 0;
      displayTimeout = 0;

      if (displayMode == DISP_TIME)
      {
        // Show current day and month in seven segement display.
        displayVal[0] = systime.mon;
        displayVal[1] = systime.mday;
        displayVal[2] = 0;

        displayMode = DISP_DATE;
      }
      else
      {
        // Return display to default (time) mode.
        displayVal[0] = formatHours(clock24hrFormat, systime.hour);
        displayVal[1] = systime.min;
        displayVal[2] = systime.sec;

        displayMode = DISP_TIME;
      }
    }
  }
}

ISR(TIMER1_COMPA_vect)
{
  // Update time from RTC.
  updateReq = true;

  // Check current display mode.
  if (displayMode == DISP_DATE)
  {
    // Clear date display in 10 seconds.
    displayTimeout++;

    if (displayTimeout >= 10)
    {
      displayTimeout = 0;
      displayMode = DISP_TIME;
    }
  }
}

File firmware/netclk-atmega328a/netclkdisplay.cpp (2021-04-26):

//---------------------------------------------------------------------------------------
// Ethernet base NTP clock panel driver.
// Support routines for Seven-segment display.
// 
// Copyright (c) 2021 Dilshan R Jayakody. [jayakody2000lk@gmail.com]
// 
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
#include "Arduino.h"
#include "netclkdisplay.h"

void setSegmentValue(unsigned char val, bool dot)
{
  switch(val)
  {
    case 0:
      // Digit "0".
      digitalWrite(2, HIGH);
      digitalWrite(3, HIGH);
      digitalWrite(4, HIGH);
      digitalWrite(5, HIGH);
      digitalWrite(6, HIGH);
      digitalWrite(7, HIGH);
      digitalWrite(8, LOW);
      break;
    case 1:
      // Digit "1".
      digitalWrite(2, LOW);
      digitalWrite(3, HIGH);
      digitalWrite(4, HIGH);
      digitalWrite(5, LOW);
      digitalWrite(6, LOW);
      digitalWrite(7, LOW);
      digitalWrite(8, LOW);
      break;
    case 2:
      // Digit "2".
      digitalWrite(2, HIGH);
      digitalWrite(3, HIGH);
      digitalWrite(4, LOW);
      digitalWrite(5, HIGH);
      digitalWrite(6, HIGH);
      digitalWrite(7, LOW);
      digitalWrite(8, HIGH);
      break;
    case 3:
      // Digit "3".
      digitalWrite(2, HIGH);
      digitalWrite(3, HIGH);
      digitalWrite(4, HIGH);
      digitalWrite(5, HIGH);
      digitalWrite(6, LOW);
      digitalWrite(7, LOW);
      digitalWrite(8, HIGH);   
      break;
    case 4:
      // Digit "4".
      digitalWrite(2, LOW);
      digitalWrite(3, HIGH);
      digitalWrite(4, HIGH);
      digitalWrite(5, LOW);
      digitalWrite(6, LOW);
      digitalWrite(7, HIGH);
      digitalWrite(8, HIGH);    
      break;
    case 5:
      // Digit "5".
      digitalWrite(2, HIGH);
      digitalWrite(3, LOW);
      digitalWrite(4, HIGH);
      digitalWrite(5, HIGH);
      digitalWrite(6, LOW);
      digitalWrite(7, HIGH);
      digitalWrite(8, HIGH);    
      break;
    case 6:
      // Digit "6".
      digitalWrite(2, HIGH);
      digitalWrite(3, LOW);
      digitalWrite(4, HIGH);
      digitalWrite(5, HIGH);
      digitalWrite(6, HIGH);
      digitalWrite(7, HIGH);
      digitalWrite(8, HIGH);
      break;
    case 7:
      // Digit "7".
      digitalWrite(2, HIGH);
      digitalWrite(3, HIGH);
      digitalWrite(4, HIGH);
      digitalWrite(5, LOW);
      digitalWrite(6, LOW);
      digitalWrite(7, LOW);
      digitalWrite(8, LOW);    
      break;
    case 8:
      // Digit "8".
      digitalWrite(2, HIGH);
      digitalWrite(3, HIGH);
      digitalWrite(4, HIGH);
      digitalWrite(5, HIGH);
      digitalWrite(6, HIGH);
      digitalWrite(7, HIGH);
      digitalWrite(8, HIGH);     
      break;
    case 9:
      // Digit "9".
      digitalWrite(2, HIGH);
      digitalWrite(3, HIGH);
      digitalWrite(4, HIGH);
      digitalWrite(5, HIGH);
      digitalWrite(6, LOW);
      digitalWrite(7, HIGH);
      digitalWrite(8, HIGH);
      break;
    default:
      // Clear (turn off) the current segment.
      digitalWrite(2, LOW);
      digitalWrite(3, LOW);
      digitalWrite(4, LOW);
      digitalWrite(5, LOW);
      digitalWrite(6, LOW);
      digitalWrite(7, LOW);
      digitalWrite(8, LOW);      
  } 

  digitalWrite(9, dot ? HIGH : LOW);
}

void selectSegment(unsigned char segment)
{
  switch(segment)
  {
    case 1:
      digitalWrite(A0, HIGH);
      digitalWrite(A1, LOW);
      digitalWrite(A2, LOW);
      digitalWrite(A3, LOW);
      break;
    case 2:
      digitalWrite(A0, LOW);
      digitalWrite(A1, HIGH);
      digitalWrite(A2, LOW);
      digitalWrite(A3, LOW);
      break;
   case 3:
      digitalWrite(A0, LOW);
      digitalWrite(A1, LOW);
      digitalWrite(A2, HIGH);
      digitalWrite(A3, LOW);
      break;
   case 4:
      digitalWrite(A0, LOW);
      digitalWrite(A1, LOW);
      digitalWrite(A2, LOW);
      digitalWrite(A3, HIGH);
      break;
   default:
      // Shutdown all segments.
      digitalWrite(A0, LOW);
      digitalWrite(A1, LOW);
      digitalWrite(A2, LOW);
      digitalWrite(A3, LOW);
  }
}

void clearDisplay()
{
  selectSegment(0);
  setSegmentValue(0xFF, false);
}

void displayTime(unsigned char *segVal)
{
  unsigned char tempVal = segVal[0] / 10;
  
  selectSegment(0);
  setSegmentValue((tempVal == 0) ? 0xFF : tempVal, false);
  selectSegment(1);
  delay(1);

  selectSegment(0);
  setSegmentValue(segVal[0] % 10, (segVal[2] % 2));
  selectSegment(2);
  delay(1);

  selectSegment(0);
  setSegmentValue(segVal[1] / 10, false);
  selectSegment(3);
  delay(1);

  selectSegment(0);
  setSegmentValue(segVal[1] % 10, false);
  selectSegment(4);
  delay(1);
}

void displaySeconds(unsigned char *segVal)
{
  selectSegment(0);
  setSegmentValue(0xFF, false);
  selectSegment(1);
  delay(1);

  selectSegment(0);
  setSegmentValue(0xFF, false);
  selectSegment(2);
  delay(1);

  selectSegment(0);
  setSegmentValue(segVal[1] / 10, false);
  selectSegment(3);
  delay(1);

  selectSegment(0);
  setSegmentValue(segVal[1] % 10, false);
  selectSegment(4);
  delay(1);
}

void initDisplay()
{
  // Configure display segment lines as output.
  pinMode(A0, OUTPUT);
  pinMode(A1, OUTPUT);
  pinMode(A2, OUTPUT);
  pinMode(A3, OUTPUT);

  // Configure display data lines as output.
  pinMode(2, OUTPUT);
  pinMode(3, OUTPUT);
  pinMode(4, OUTPUT);
  pinMode(5, OUTPUT);

  pinMode(6, OUTPUT);
  pinMode(7, OUTPUT);
  pinMode(8, OUTPUT);
  pinMode(9, OUTPUT);

  // Clear all the segments of the seven segment display.
  clearDisplay();
}

void activateRefreshTimer()
{
  noInterrupts();
  
  // Enable timer1.
  TCCR1A = 0;
  TCCR1B = 0;
  TCNT1  = 0;

  // Set timer 1 to 1Hz.
  OCR1A = 15624;

  // Enable timer 1 compare interrupt and set prescaler to 256.
  TCCR1B |= (1 << WGM12);
  TCCR1B |= (1 << CS12) | (1 << CS10); 
  TIMSK1 |= (1 << OCIE1A);

  interrupts();
}

unsigned char formatHours(bool hr24, unsigned char hr)
{
  if(hr24)
  {
    // 24-hour clock format.
    return hr;
  }
  else
  {
    // 12-hour clock format.
    return (hr > 12) ? (hr - 12) : hr;
  }
}

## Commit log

2021-04-26 Initial version of NTP clock driver source code and design files.
    [netclock.kicad_pcb, netclock.sch]
2021-04-26 Add prototype image the readme.md file.
2021-04-27 Add NTP clock driver connection diagram.
    [CONTROL-BTN.sch, SSD-LAYOUT.sch, netclock-wirelayout.sch]
2021-04-27 Update 7-segment display details in the wiring layout.
    [CONTROL-BTN.sch, SSD-LAYOUT.sch]
2021-04-27 Add PDF version of wiring layout.
2021-04-27 Add link to the PCBWay store.

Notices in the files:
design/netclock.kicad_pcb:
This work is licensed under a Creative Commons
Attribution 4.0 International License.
